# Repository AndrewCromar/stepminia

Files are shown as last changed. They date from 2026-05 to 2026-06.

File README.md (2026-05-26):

# Stepminia

Desktop finger stepmania dance-pad.

Assebly instructions [here](ASSEMBLY.md).

## PCB

Made in Kicad. Find the production files in the pcb folder to have it manufacured (JLCPCB).

You may notice the simple and integrated pcbs. This is because I wanted to learn how to integrate a microcontroller (rp2040) into my pcb design.. but when I went to have it made it was gonna cost $100! Its not that much but I have other things I wanna buy right now. So I made the simple version that just has holes for a Waveshare Zero to be soldered on.

## Firmware

The firmware is in the firmware folder and there will likly be a compiled version of it also in that folder.

> Wow really I had no clue the firmware would be in that folder bro.

## CAD

Right now I'm making the cad stuff in OnShape so I dont have files for it. I'll download the stls and put them in the cad folder when I'm done with them.

> I also my link to the OnShape files and/or download the files as solidworks parts if I can so people can make changes.

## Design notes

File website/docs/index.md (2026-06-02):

# Stepminia

Mini Stepmania dance-pad for desktop finger gaming.

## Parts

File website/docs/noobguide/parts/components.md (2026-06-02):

# Components

Gather the following components.

| Part | Count | Amazon Link | Image |
| ---- | ----- | --- | ----- |
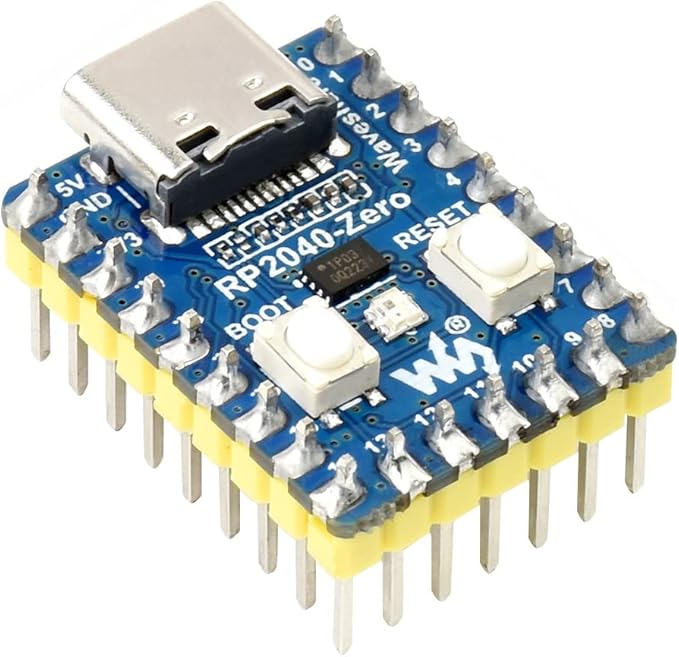
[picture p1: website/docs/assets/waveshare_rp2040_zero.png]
WaveShare RP2040-Zero
| WaveShare RP2040-Zero with Header | 1x | [link](https://a.co/d/0eX9dTef) |  |
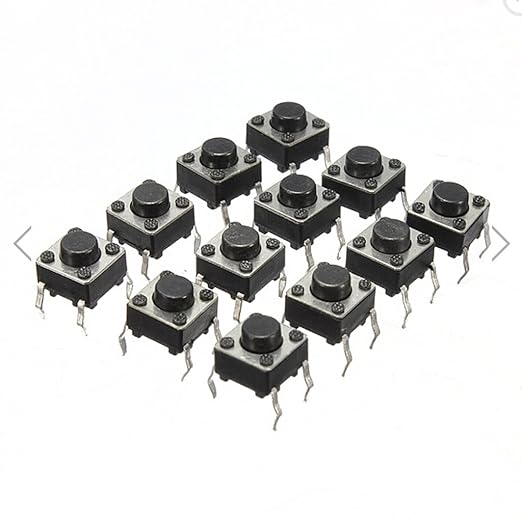
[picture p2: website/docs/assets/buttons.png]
Buttons
| Buttons | 2x | [link](https://a.co/d/03LZRInP) |  |
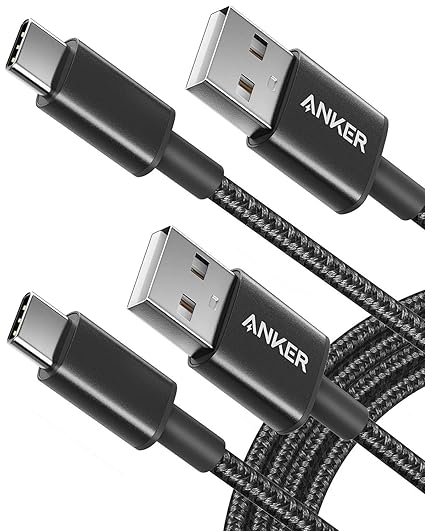
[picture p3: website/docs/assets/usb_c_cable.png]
USB-C cable
| USB-C Cable | 1x | [link](https://a.co/d/04qqzBDn) |  |

!!! note
    The links are recommended parts. You can find your own source to buy them if you want.

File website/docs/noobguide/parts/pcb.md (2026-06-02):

# PCB

The pcb (or circuit board) will be the main part that is needed for the device to work.

This section will guide you through downloading the files to having them manufactured.

## Download

[Click here to download the production files.](https://github.com/AndrewCromar/stepminia/raw/main/pcb/simple/production.zip)

## Manufacturing via JLC

1. [Open JLCPCB.](https://jlcpcb.com/)
2. Sign in or create an account.
3. Click the `Order Now` button.
4. Click the `Add gerber file` button and select the `production.zip` file you just downloaded.
5. You can leave all the settings default.
6. Click the `Save To Cart` button.
7. Go to your cart and checkout via the `Secure Checkout` button.

Your pcb has been ordered!

## Example

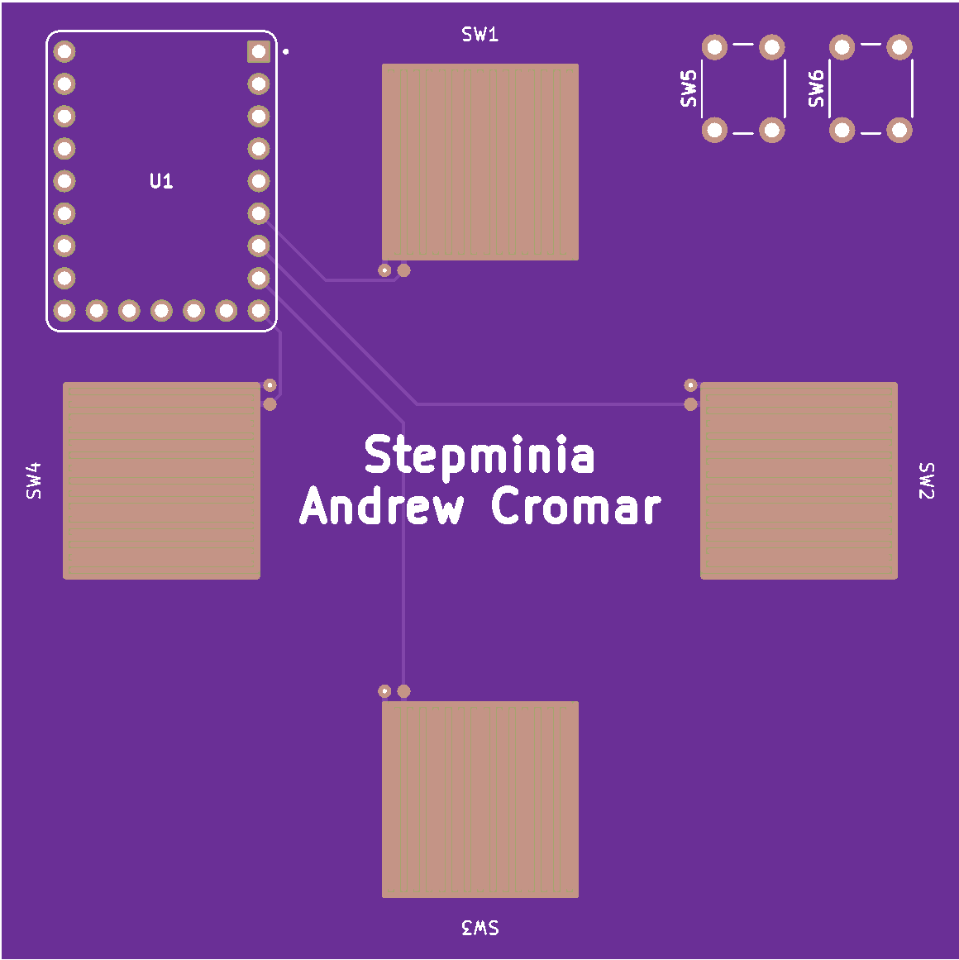
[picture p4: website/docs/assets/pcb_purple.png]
USB-C cable


!!! note
    Your pcb will likly be green but you can choose the color at step 5.

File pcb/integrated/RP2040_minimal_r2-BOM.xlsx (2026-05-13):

RP2040_minimal_r2 BOM
Item | Quantity | Reference | Part | Voltage | Current | Power | Material | Size | Tolerance | Manufacturer | Manuf. Part # | Description | Notes
1 | 3 | C1,C4,C17 | 10u | 16V |  |  | X5R | 0805_2012Metric | 10% | Murata | GRM21BR61C106KE15K | CAP CER 10UF 16V X5R 0805 | Or equivalent
2 | 2 | C2, C3 | 15p | 50V |  |  | C0G | 0402_1005Metric | 5% | Murata | GCM1555C1H150JA16D | CAP CER 15PF 50V C0G/NP0 0402 | Or equivalent
3 | 10 | C5, C6, C7, C9, C11, C12, C13, C14, C15, C16 | 100n | 25V |  |  | X7R | 0402_1005Metric | 10% | Murata | GRM155R71E104KE14J | CAP CER 0.1UF 25V X7R 0402 | Or equivalent
4 | 2 | C8, C10 | 1u | 10V |  |  | X6S | 0402_1005Metric | 10% | Murata | GRM155C81A105KA12D | CAP CER 1UF 10V X6S 0402 | Or equivalent
5 | 1 | J1 | USB_B_Micro |  |  |  |  |  |  | Amphenol | 10103594-0001LF | CONN RCPT USB2.0 MICRO B SMD R/A | Or equivalent
6 | 1 | J2 | 1x2 way header |  |  |  |  |  |  | Samtec | TSW-102-23-T-S | 2.54mm pin header 1x2 | Or equivalent
7 | 2 | J3, J4 | 2x18 way header |  |  |  |  |  |  | Samtec | TSW-118-23-T-D | 2.54mm pin header 2x18 | Or equivalent
8 | 2 | R1, R5 | 1k |  |  | 63mW |  | 0402_1005Metric | 1% | Yageo | RC0402FR-071KP | RES SMD 1K OHM 1% 1/16W 0402 | Or equivalent
9 | 1 | R2 | DNF |  |  |  |  | 0402_1005Metric |  |  |  |  | Do Not Fit
10 | 2 | R3, R4 | 27.4 |  |  | 63mW |  | 0402_1005Metric | 1% | Yageo | RC0402FR-0727R4L | RES SMD 27.4 OHM 1% 1/16W 0402 | Or equivalent
11 | 1 | U1 | NCP1117-3.3 |  |  |  |  | SOT-223-3 |  | ON Semiconductor | NCP1117ST33T3G | IC REG LINEAR 3.3V 1A SOT223
12 | 1 | U2 | W25Q128JVS |  |  |  |  | SOIC-8 |  | Winbond | W25Q128JVSIQ TR | IC FLASH 128M SPI 133MHZ 8SOIC
13 | 1 | U3 | RP2040 |  |  |  |  | QFN56 |  | Raspberry Pi | RP2040
14 | 1 | Y1 | ABM8-272-T3 |  |  |  |  | SMD_3225 |  | Abracon | ABM8-272-T3 | CRYSTAL 12.0000MHZ 3.2x2.5MM SMD

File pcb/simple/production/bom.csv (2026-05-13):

Designator | Footprint | Quantity | Value | LCSC Part #
SW1 | DDR_CONTACT | 1 | DDR_North
SW2 | DDR_CONTACT | 1 | DDR_East
SW3 | DDR_CONTACT_MIRROR | 1 | DDR_South
SW4 | DDR_CONTACT_MIRROR | 1 | DDR_West
SW5 | SW_PUSH_6mm | 1 | SW_Pause
SW6 | SW_PUSH_6mm | 1 | SW_Start
U1 | MODULE_RP2040-ZERO | 1 | RP2040-ZERO

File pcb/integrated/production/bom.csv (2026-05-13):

Designator | Footprint | Quantity | Value | LCSC Part #
C1, C17, C4 | 0805 | 3 | 10u | C440198
C10, C8 | 0402 | 2 | 1u | C29266
C11, C12, C13, C14, C15, C16, C5, C6, C7, C9 | 0402 | 10 | 100n | C60474
C2, C3 | 0402 | 2 | 15p | C86285
J2 | PinHeader_1x02_P2.54mm_Vertical | 1 | Conn_01x02
J3 | USB_C_Receptacle_GCT_USB4105-xx-A_16P_TopMnt_Horizontal | 1 | USB_C_Receptacle | C2765186
R1, R5 | 0402 | 2 | 1k | C106235
R2 | 0402 | 1 | 10k | C60490
R3, R4 | 0402 | 2 | 27 | C138021
R6, R7 | 0402 | 2 | 5.1k | C105872
SW1 | DDR_CONTACT_MIRROR | 1 | DDR_North
SW2 | DDR_CONTACT | 1 | DDR_South
SW3 | DDR_CONTACT | 1 | DDR_East
SW4 | DDR_CONTACT | 1 | DDR_West
U1 | SOT-223-3_TabPin2 | 1 | NCP1117-3.3_SOT223 | C26537
U2 | SOIC-8_5.23x5.23mm_P1.27mm | 1 | W25Q128JVS | C113767
U3 | RP2040-QFN-56 | 1 | RP2040 | C2040
Y1 | Crystal_SMD_3225-4Pin_3.2x2.5mm | 1 | ABM8-272-T3 | C20625731

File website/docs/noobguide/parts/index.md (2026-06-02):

# Gathering Parts

First you will need to gather all the parts to build your pad.

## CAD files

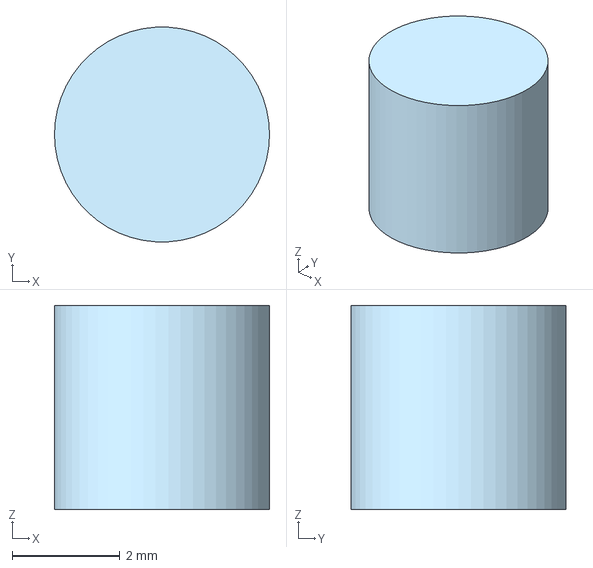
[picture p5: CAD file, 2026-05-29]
cad/Spacer - Spacer.step
4.00 x 3.99 x 3.80 mm

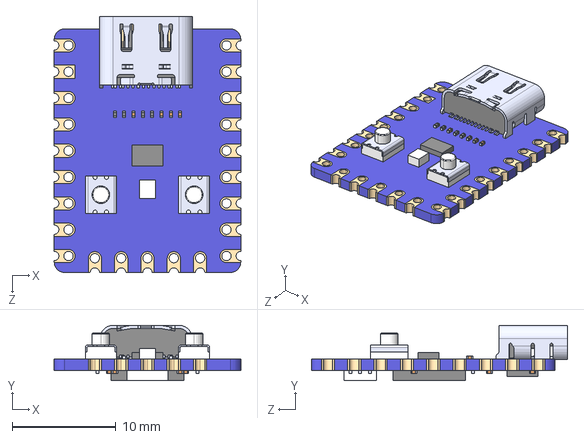
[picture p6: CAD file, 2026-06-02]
pcb/simple/RP2040-ZERO/RP2040-ZERO.step
18.0 x 5.35 x 24.7 mm

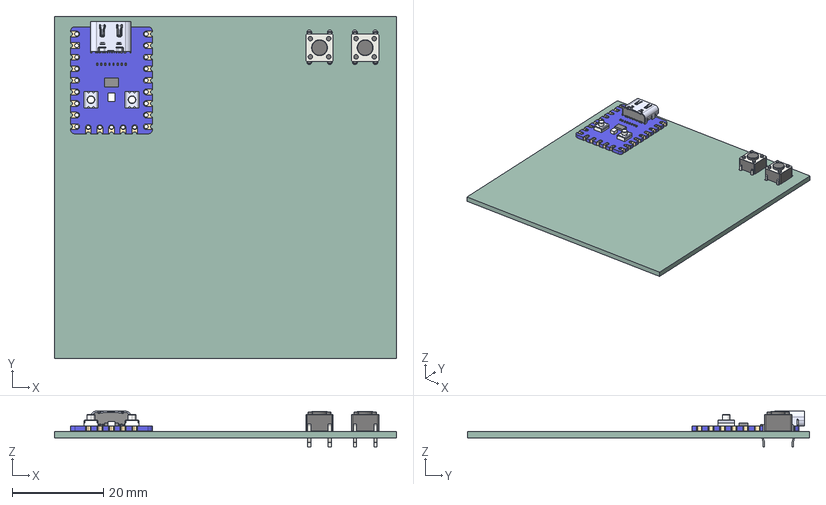
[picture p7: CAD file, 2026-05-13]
pcb/simple/stepminia_pcb.step
75.0 x 75.0 x 7.85 mm
RP2040-ZERO
SW_PUSH_6mm x 2
pcb_PCB

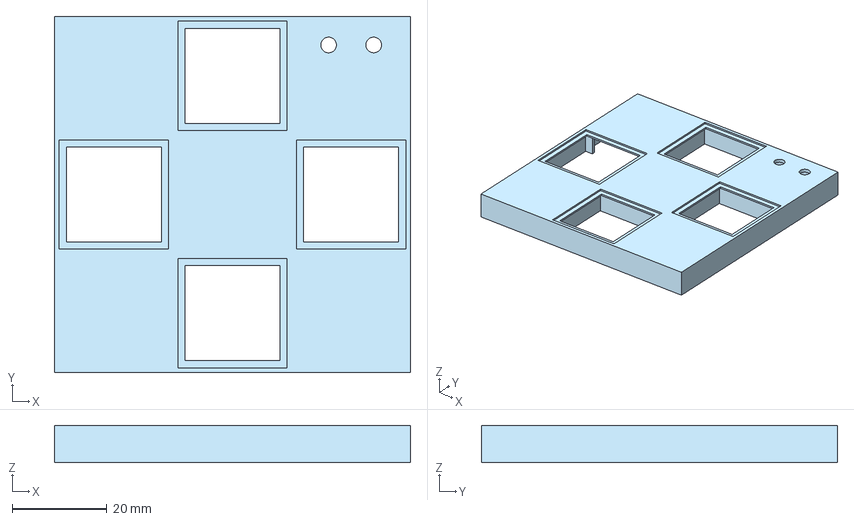
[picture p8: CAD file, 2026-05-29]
cad/All Nonants.step
75.0 x 75.0 x 7.80 mm

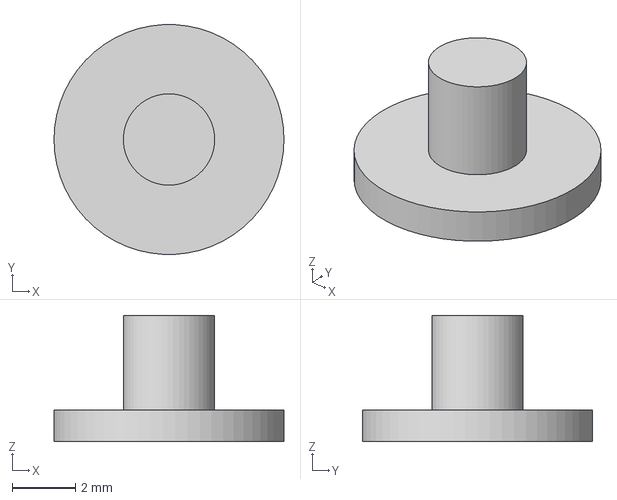
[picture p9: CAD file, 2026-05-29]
cad/Button - Button.step
7.30 x 7.29 x 4.00 mm

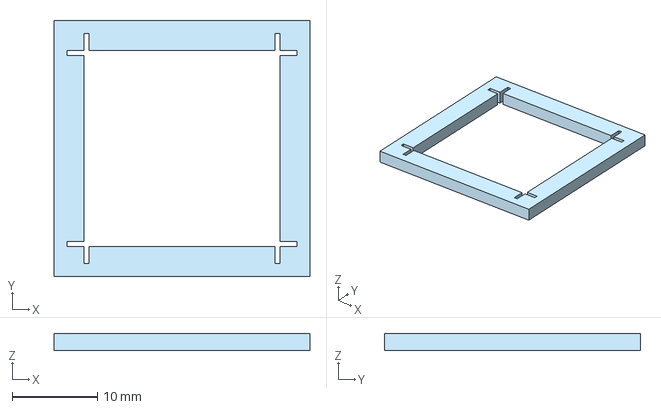
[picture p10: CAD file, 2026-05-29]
cad/Pad Guide - Pad Guide.step
30.0 x 30.0 x 2.00 mm

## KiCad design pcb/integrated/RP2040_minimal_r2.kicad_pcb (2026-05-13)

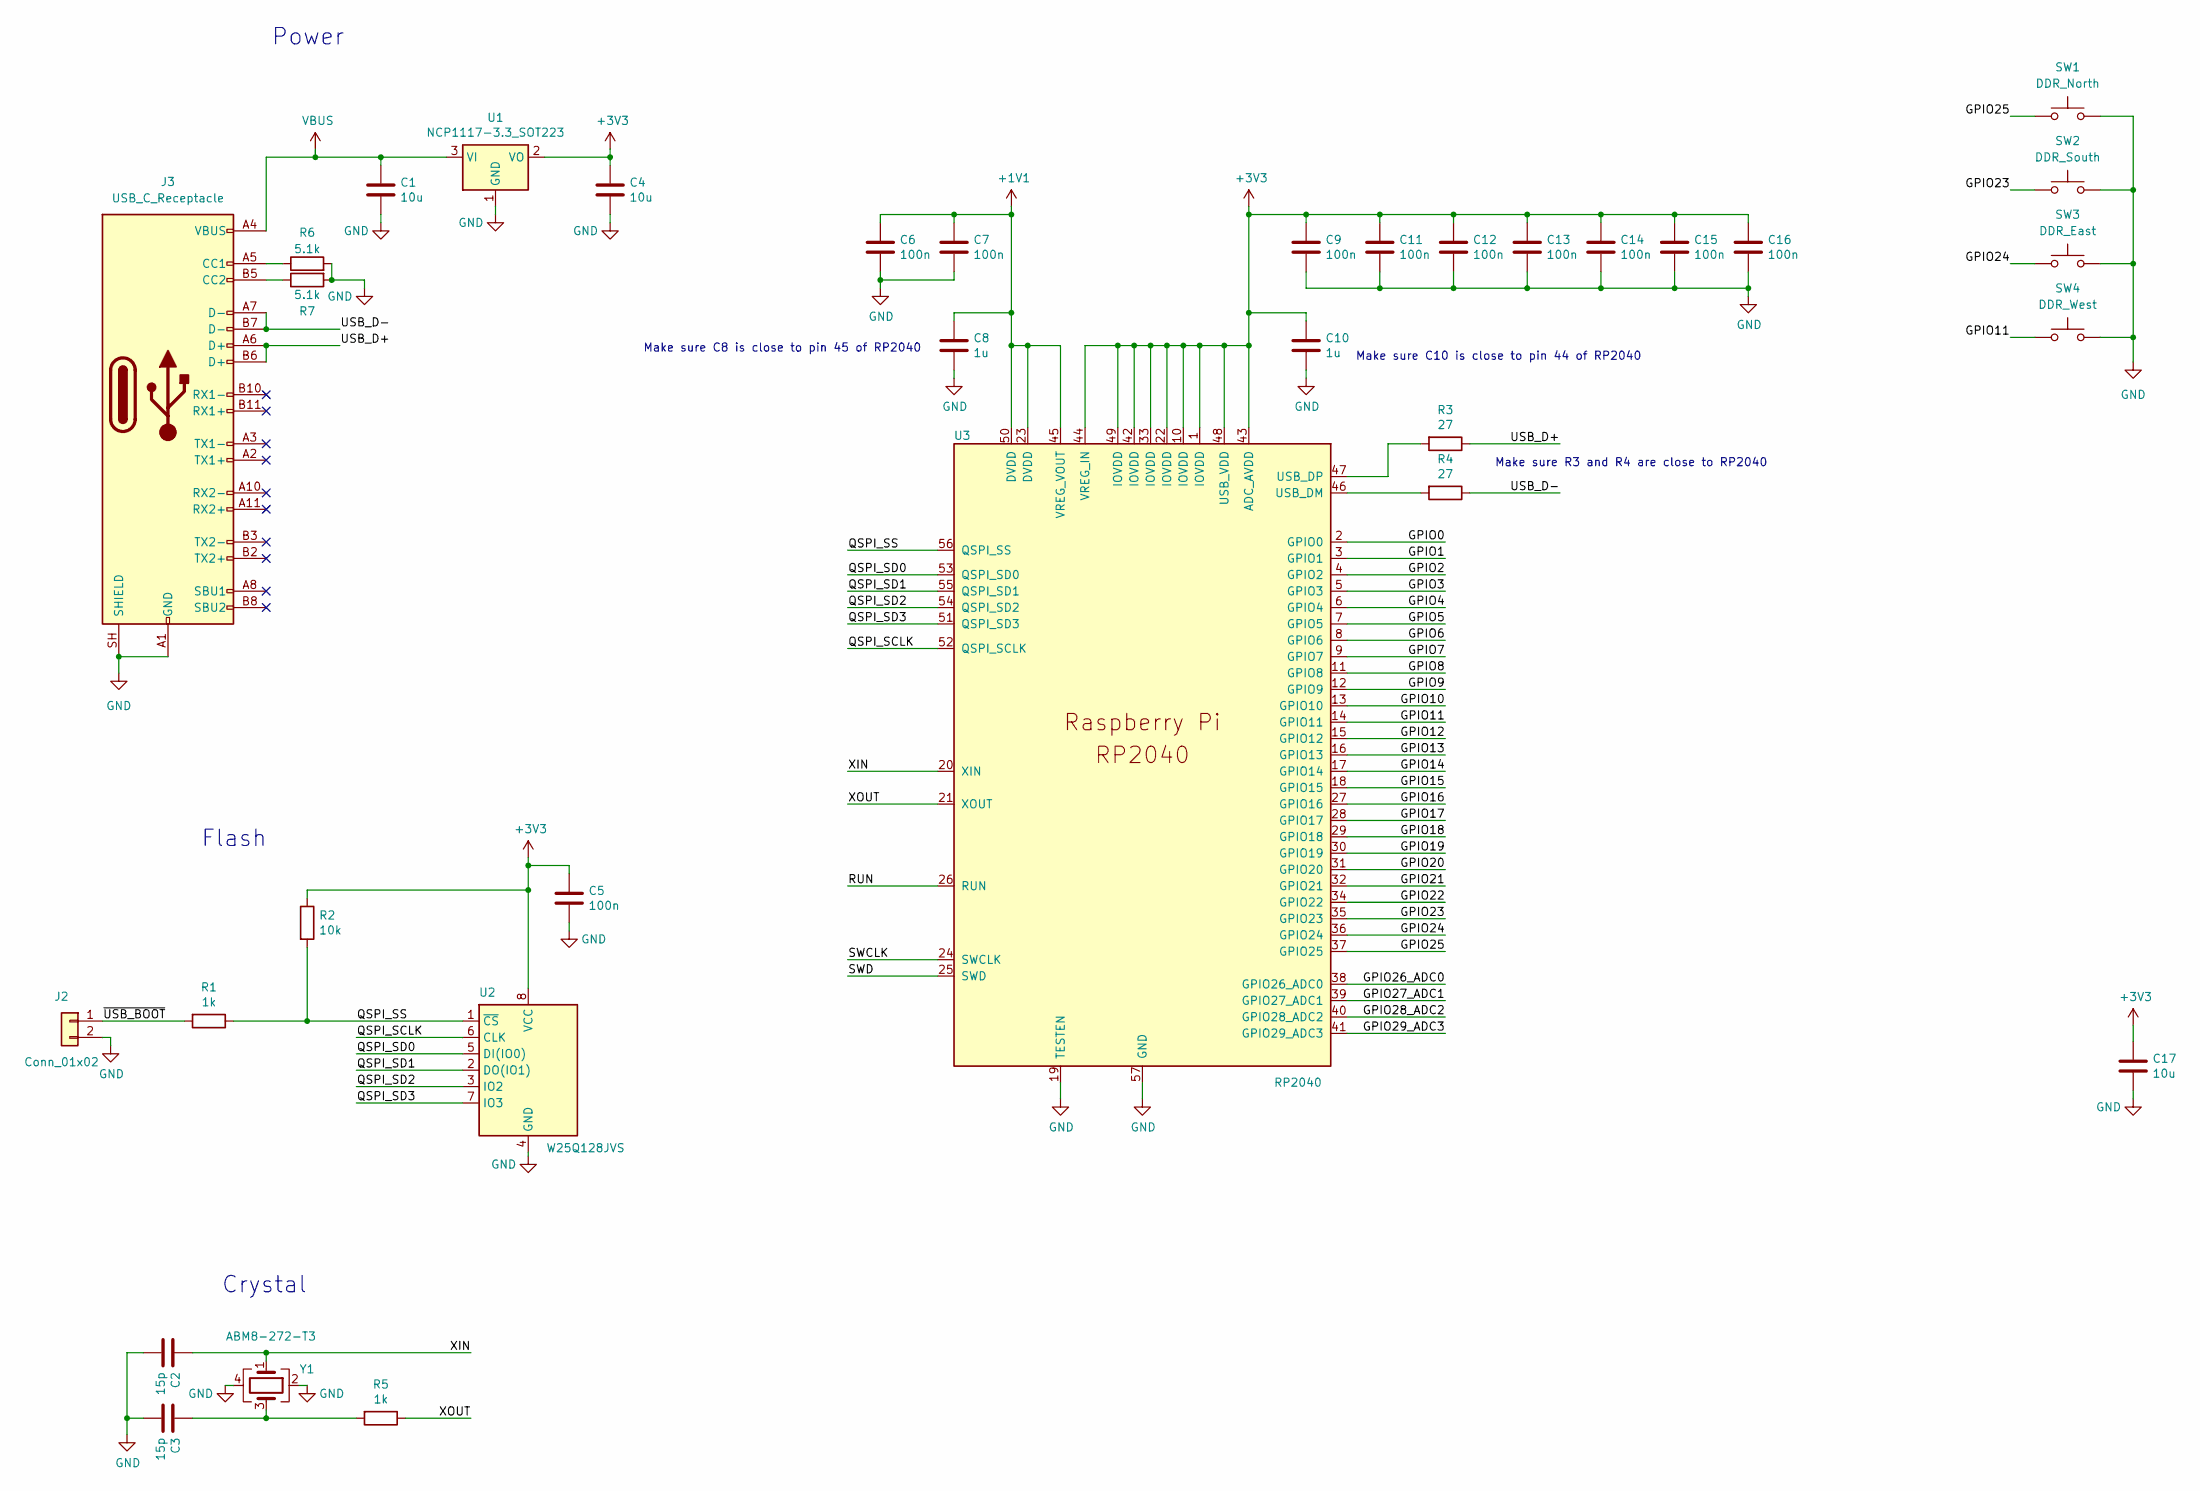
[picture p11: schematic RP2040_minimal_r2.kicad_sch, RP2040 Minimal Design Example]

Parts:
C1, C4, C17: 10u; C_0805_2012Metric; LCSC C440198
C2, C3: 15p; C_0402_1005Metric; LCSC C86285
C5, C6, C7, C9, C11, C12, C13, C14, C15, C16: 100n; C_0402_1005Metric; LCSC C60474
C8, C10: 1u; C_0402_1005Metric; LCSC C29266
J2: Conn_01x02; PinHeader_1x02_P2.54mm_Vertical
J3: USB_C_Receptacle; USB_C_Receptacle_GCT_USB4105-xx-A_16P_TopMnt_Horizontal; LCSC C2765186
R1, R5: 1k; R_0402_1005Metric; LCSC C106235
R2: 10k; R_0402_1005Metric; LCSC C60490
R3, R4: 27; R_0402_1005Metric; LCSC C138021
R6, R7: 5.1k; R_0402_1005Metric; LCSC C105872
SW1: DDR_North; DDR_CONTACT_MIRROR
SW2: DDR_South; DDR_CONTACT
SW3: DDR_East; DDR_CONTACT
SW4: DDR_West; DDR_CONTACT
U1: NCP1117-3.3_SOT223; SOT-223-3_TabPin2; LCSC C26537
U2: W25Q128JVS; SOIC-8_5.23x5.23mm_P1.27mm; LCSC C113767
U3: RP2040; RP2040-QFN-56; LCSC C2040
Y1: ABM8-272-T3; Crystal_SMD_3225-4Pin_3.2x2.5mm; LCSC C20625731

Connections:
+1V1: C6.1, C7.1, C8.1, U3.23 (DVDD), U3.45 (VREG_VOUT), U3.50 (DVDD)
+3V3: C4.1, C5.1, C9.1, C10.1, C11.1, C12.1, C13.1, C14.1, C15.1, C16.1, C17.1, R2.1, U1.2 (VO), U2.8 (VCC), U3.1 (IOVDD), U3.10 (IOVDD), U3.22 (IOVDD), U3.33 (IOVDD), U3.42 (IOVDD), U3.43 (ADC_AVDD), U3.44 (VREG_IN), U3.48 (USB_VDD), U3.49 (IOVDD)
/GPIO0: U3.2 (GPIO0)
/GPIO1: U3.3 (GPIO1)
/GPIO2: U3.4 (GPIO2)
/GPIO3: U3.5 (GPIO3)
/GPIO4: U3.6 (GPIO4)
/GPIO5: U3.7 (GPIO5)
/GPIO6: U3.8 (GPIO6)
/GPIO7: U3.9 (GPIO7)
/GPIO8: U3.11 (GPIO8)
/GPIO9: U3.12 (GPIO9)
/GPIO10: U3.13 (GPIO10)
/GPIO11: SW4.1, U3.14 (GPIO11)
/GPIO12: U3.15 (GPIO12)
/GPIO13: U3.16 (GPIO13)
/GPIO14: U3.17 (GPIO14)
/GPIO15: U3.18 (GPIO15)
/GPIO16: U3.27 (GPIO16)
/GPIO17: U3.28 (GPIO17)
/GPIO18: U3.29 (GPIO18)
/GPIO19: U3.30 (GPIO19)
/GPIO20: U3.31 (GPIO20)
/GPIO21: U3.32 (GPIO21)
/GPIO22: U3.34 (GPIO22)
/GPIO23: SW2.1, U3.35 (GPIO23)
/GPIO24: SW3.1, U3.36 (GPIO24)
/GPIO25: SW1.1, U3.37 (GPIO25)
/GPIO26_ADC0: U3.38 (GPIO26_ADC0)
/GPIO27_ADC1: U3.39 (GPIO27_ADC1)
/GPIO28_ADC2: U3.40 (GPIO28_ADC2)
/GPIO29_ADC3: U3.41 (GPIO29_ADC3)
/QSPI_SCLK: U2.6 (CLK), U3.52 (QSPI_SCLK)
/QSPI_SD0: U2.5 (DI(IO0)), U3.53 (QSPI_SD0)
/QSPI_SD1: U2.2 (DO(IO1)), U3.55 (QSPI_SD1)
/QSPI_SD2: U2.3 (IO2), U3.54 (QSPI_SD2)
/QSPI_SD3: U2.7 (IO3), U3.51 (QSPI_SD3)
/QSPI_SS: R1.1, R2.2, U2.1 (~CS), U3.56 (QSPI_SS)
/RUN: U3.26 (RUN)
/SWCLK: U3.24 (SWCLK)
/SWD: U3.25 (SWD)
/USB_D+: J3.A6 (D+), J3.B6 (D+), R3.1
/USB_D-: J3.A7 (D-), J3.B7 (D-), R4.1
/XIN: C2.1, U3.20 (XIN), Y1.1
/XOUT: R5.1, U3.21 (XOUT)
/~USB_BOOT: J2.1, R1.2
GND: C1.2, C2.2, C3.2, C4.2, C5.2, C6.2, C7.2, C8.2, C9.2, C10.2, C11.2, C12.2, C13.2, C14.2, C15.2, C16.2, C17.2, J2.2, J3.A1 (GND), J3.A12 (GND), J3.B1 (GND), J3.B12 (GND), J3.SH (SHIELD), R6.2, R7.2, SW1.2, SW2.2, SW3.2, SW4.2, U1.1 (GND), U2.4 (GND), U3.19 (TESTEN), U3.57 (GND), Y1.2, Y1.4
unnamed: C3.1, R5.2, Y1.3
unnamed: J3.A5 (CC1), R6.1
unnamed: J3.B5 (CC2), R7.1
unnamed: R4.2, U3.46 (USB_DM)
unnamed: R3.2, U3.47 (USB_DP)
VBUS: C1.1, J3.A4 (VBUS), J3.A9 (VBUS), J3.B4 (VBUS), J3.B9 (VBUS), U1.3 (VI)

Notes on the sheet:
Power
Crystal
Make sure C8 is close to pin 45 of RP2040
Make sure C10 is close to pin 44 of RP2040
Make sure R3 and R4 are close to RP2040
Flash

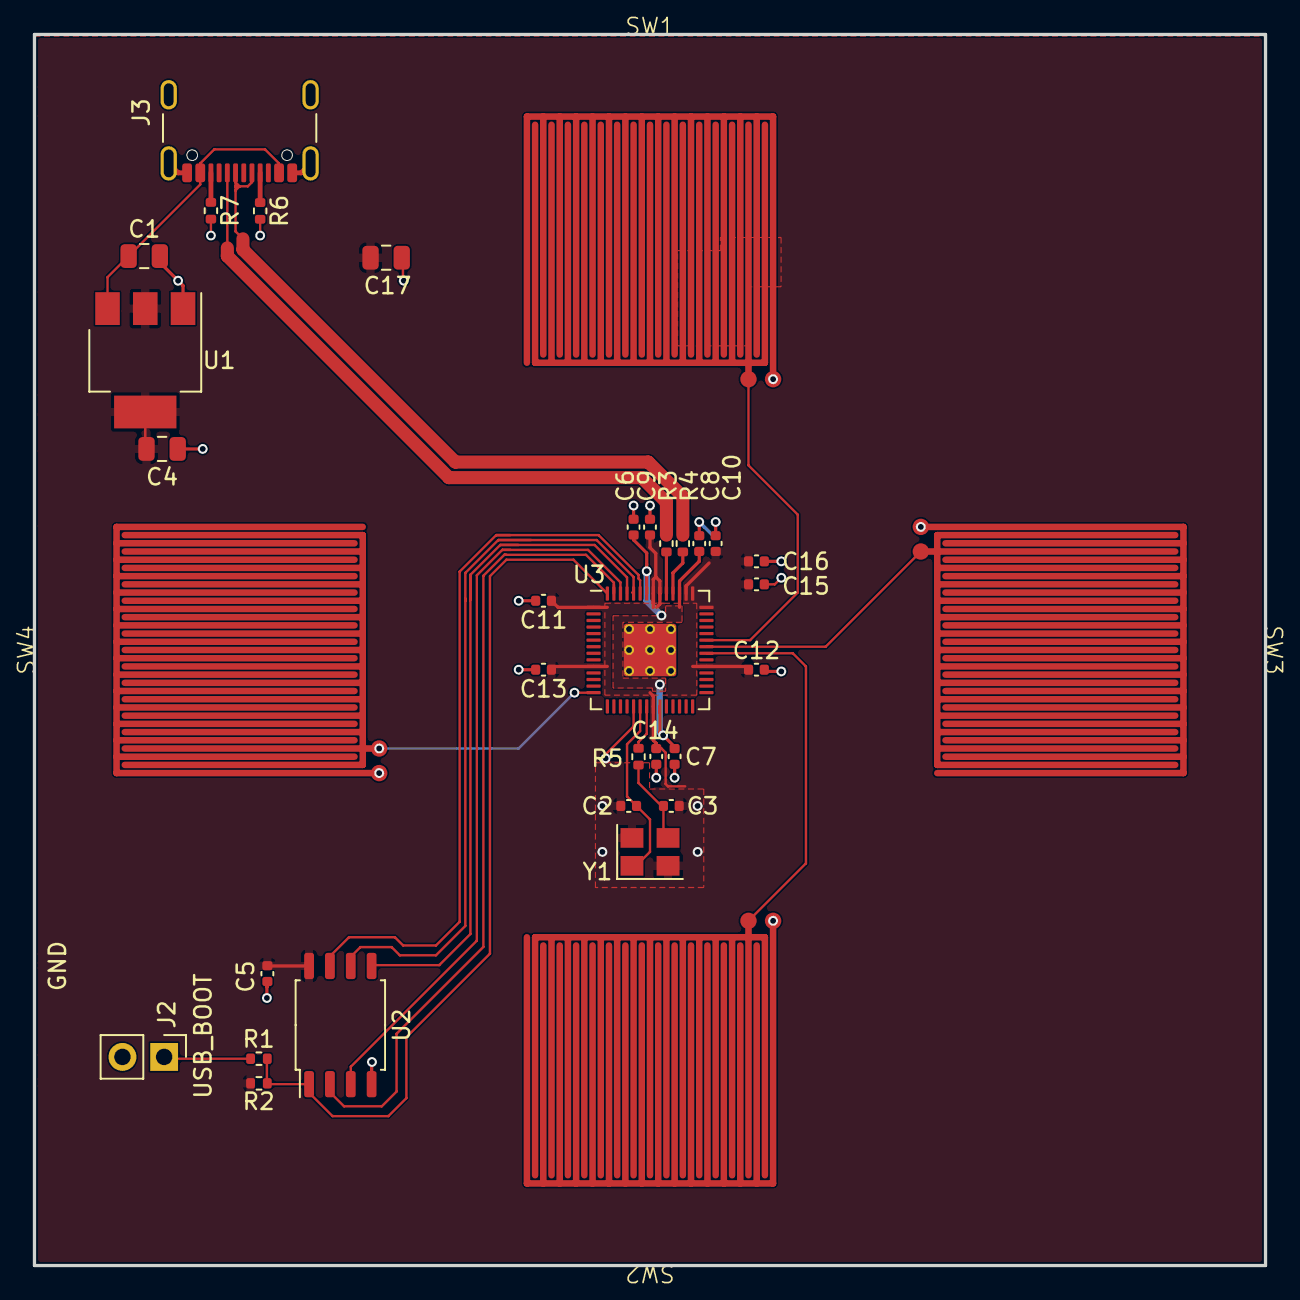
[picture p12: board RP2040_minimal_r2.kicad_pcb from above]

Board: 2 copper layers, 75.0 x 75.0 mm, 34 parts (0 on the bottom side), 24 nets.

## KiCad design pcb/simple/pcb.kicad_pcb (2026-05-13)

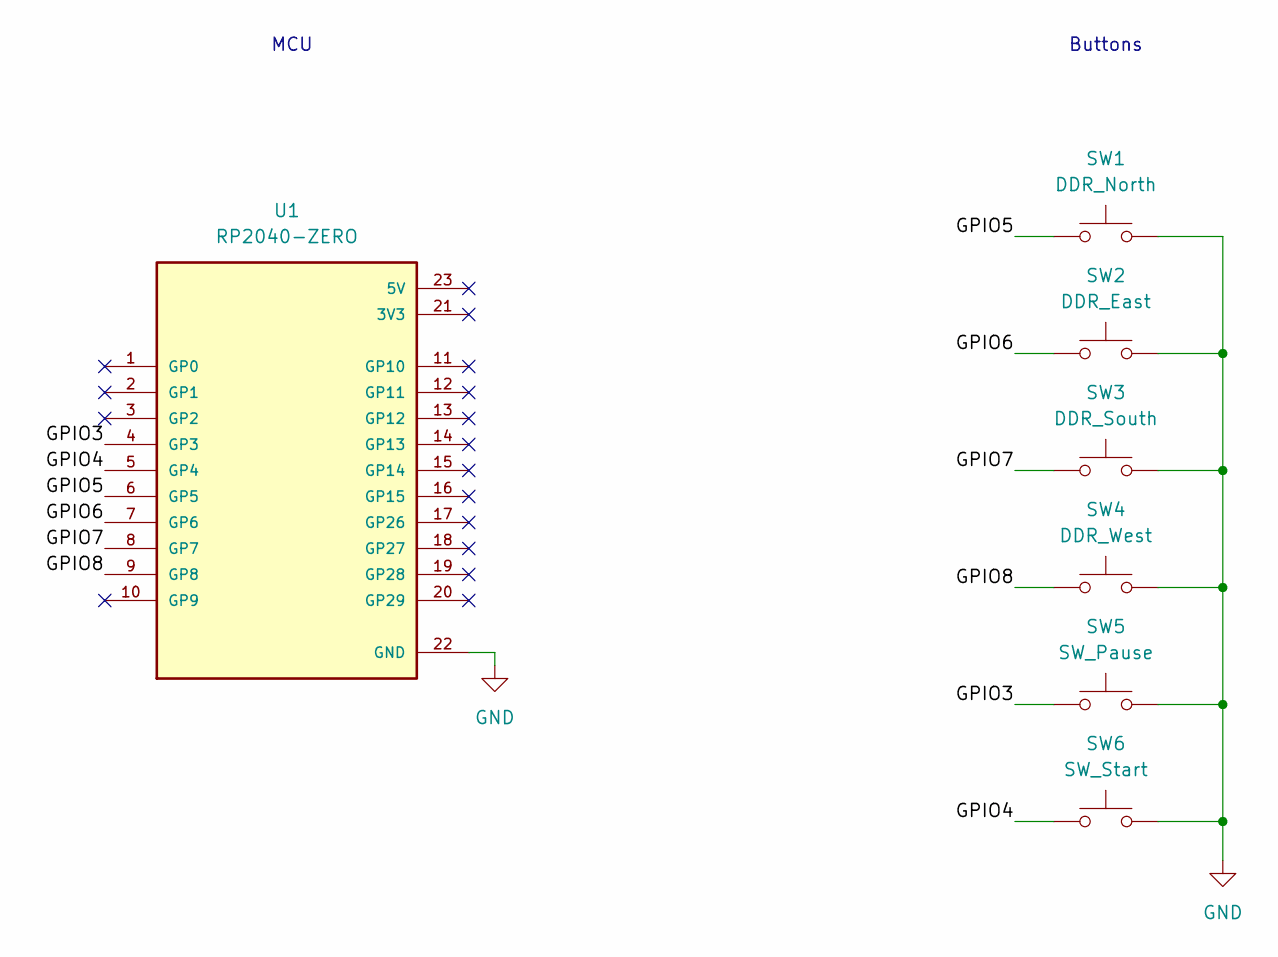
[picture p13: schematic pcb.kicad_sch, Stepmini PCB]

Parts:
SW1: DDR_North; DDR_CONTACT
SW2: DDR_East; DDR_CONTACT
SW3: DDR_South; DDR_CONTACT_MIRROR
SW4: DDR_West; DDR_CONTACT_MIRROR
SW5: SW_Pause; SW_PUSH_6mm
SW6: SW_Start; SW_PUSH_6mm
U1: RP2040-ZERO; MODULE_RP2040-ZERO; PARTREV NA

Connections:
/GPIO3: SW5.1, U1.4 (GP3)
/GPIO4: SW6.1, U1.5 (GP4)
/GPIO5: SW1.1, U1.6 (GP5)
/GPIO6: SW2.1, U1.7 (GP6)
/GPIO7: SW3.1, U1.8 (GP7)
/GPIO8: SW4.1, U1.9 (GP8)
GND: SW1.2, SW2.2, SW3.2, SW4.2, SW5.2, SW6.2, U1.22 (GND)

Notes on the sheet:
MCU
Buttons

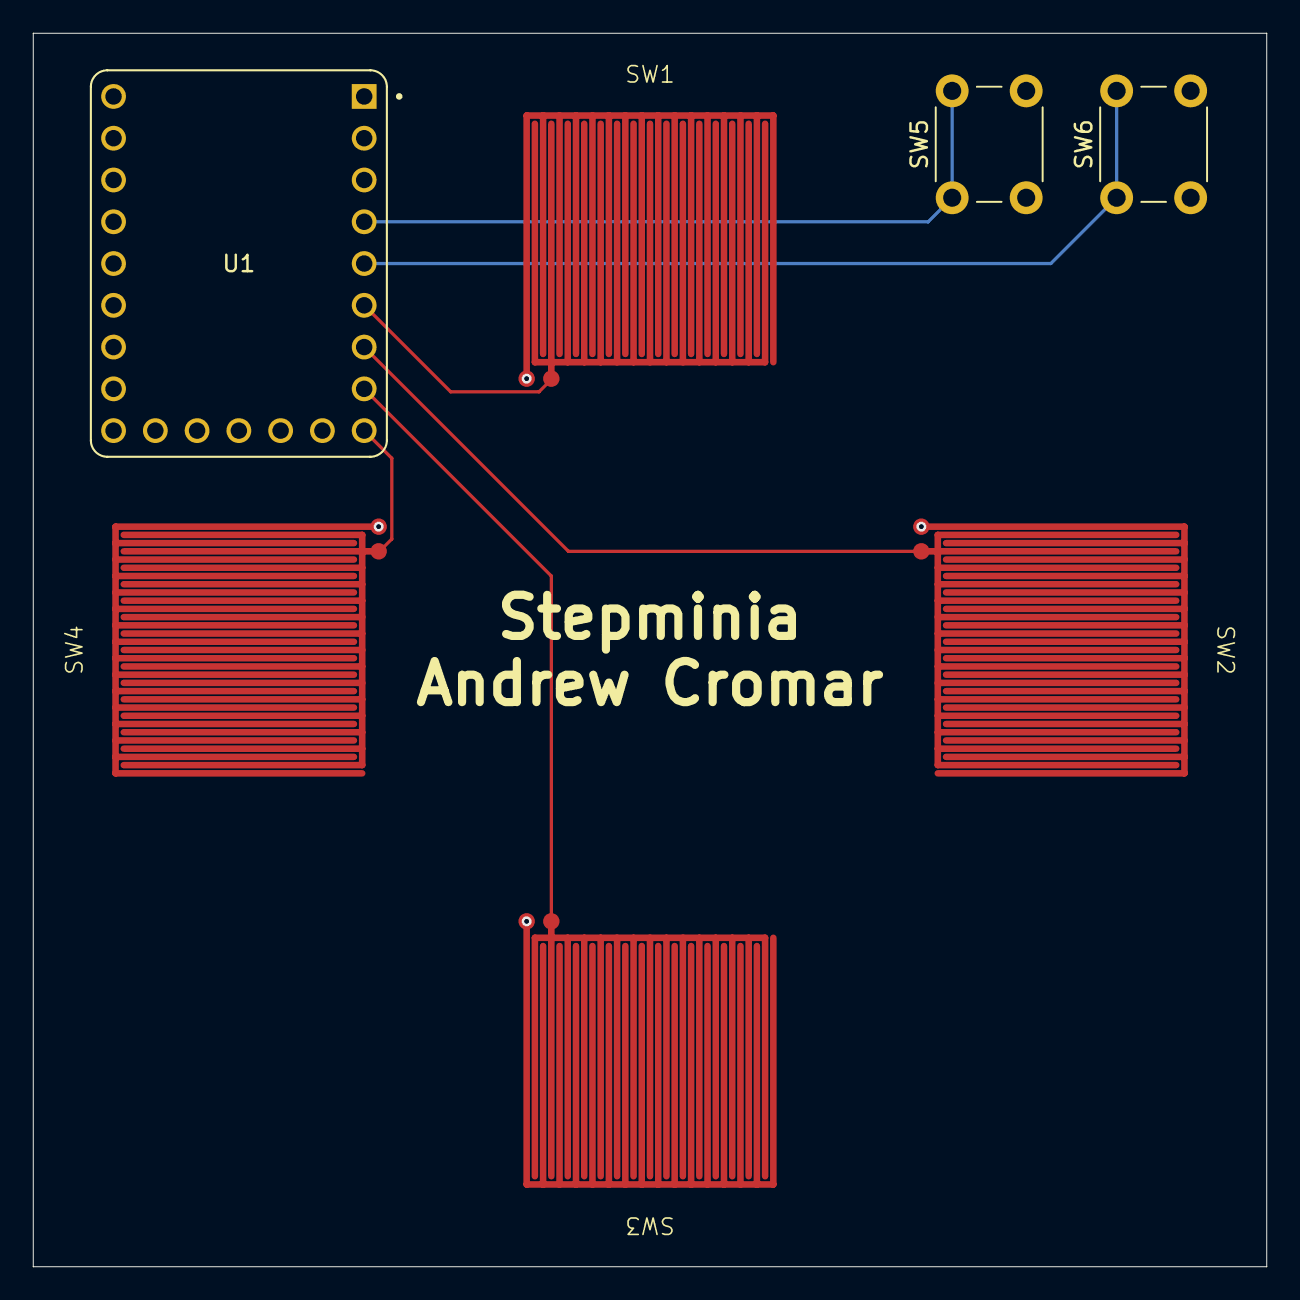
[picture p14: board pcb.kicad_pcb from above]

Board: 2 copper layers, 75.0 x 75.0 mm, 7 parts (0 on the bottom side), 7 nets.

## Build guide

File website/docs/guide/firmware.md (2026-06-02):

# Firmware

The firmware is the program that runs on the RP2040. Once it's installed, the
pad shows up to your computer as a plain USB keyboard, no drivers or extra
software needed. Each button or contact pad simply types a key.

## What it does

When you press a button (or bridge a contact pad), the pad sends a key press:

| Input | Key sent |
| --- | --- |
| Up | Arrow Up |
| Down | Arrow Down |
| Left | Arrow Left |
| Right | Arrow Right |
| Plus (+) | Enter |
| Minus (−) | Escape |

These are the keys Stepmania (and most rhythm games) use by default, so the pad
works out of the box.

## Get the firmware

The easy option is the **pre-compiled file**, a single `.uf2` you drag onto the
board, no tools required.

- [Download the pre-compiled `.uf2`](https://github.com/AndrewCromar/stepminia/raw/main/firmware/stepminia.uf2) — recommended.
- [Firmware source code](https://github.com/AndrewCromar/stepminia/tree/main/firmware) (`repo/firmware/`) — if you want to read or change it.

## Install it

1. **Unplug** the pad from your computer.
2. Hold down the `BOOTSEL` button on the RP2040, and *while holding it*, plug the
   pad back into your computer.
3. The pad mounts as a USB drive. You can
   let go of the button now.
4. **Drag the `.uf2` file onto that drive.**

The pad reboots automatically and the drive disappears, that's normal, it means
the firmware installed. It's now running as a keyboard.

## Test it

Press any button, or bridge two contact pads together (a strip of aluminum foil
works well), and check that the matching key registers. The
[keyboard tester](https://keyboard-tester.com/) site is a quick way to see your
presses live in the browser.

## Build it yourself (optional)

The source is a [PlatformIO](https://platformio.org/) project for the Waveshare
RP2040-Zero. With PlatformIO installed, open the `firmware/` folder and run:

```bash
pio run            # compile
pio run -t upload  # compile and flash a connected board
```

Compiling also produces a fresh `stepminia.uf2` you can install by hand using the
steps above.

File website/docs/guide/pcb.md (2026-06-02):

# PCB

The PCB is the heart of the pad. It carries the RP2040 microcontroller, contact pads, and buttons. There are two versions to choose from.

## Which version should I choose?

| Version | RP2040 | Best for |
| --- | --- | --- |
| **Simple** | A separate [Waveshare RP2040-Zero](https://www.waveshare.com/wiki/RP2040-Zero) board solders onto pads on the PCB. | Beginners, or anyone who'd rather solder one pre-made module than place lots of small parts. Cheaper to start, easier to assemble by hand. |
| **Integrated** | The RP2040 chip is mounted directly on the board, no second board needed. | A cleaner, single-board build. Requires placing many very small parts, so it's better suited to a PCB-assembly service or experienced solderers. |

Pick whichever matches your skill level and budget, both produce the same finished Stepminia pad.

## Getting the files

For each version you have two options:

- **Order it as-is**, download the ready-made JLCPCB production `.zip` and
  upload it straight to [JLCPCB](https://jlcpcb.com/) (or a similar fab house).
  This is the fast path.
- **Open or edit the design**, grab the [KiCad](https://www.kicad.org/) source
  if you want to inspect, modify, or regenerate the board yourself.

!!! note
    Using the ready-made production files is recommended.

### Simple

- [Download JLCPCB production files (.zip)](https://github.com/AndrewCromar/stepminia/raw/main/pcb/simple/production.zip).
- [KiCad source files](https://github.com/AndrewCromar/stepminia/tree/main/pcb/simple) (`repo/pcb/simple/`).

### Integrated

- [Download JLCPCB production files (.zip)](https://github.com/AndrewCromar/stepminia/raw/main/pcb/integrated/production.zip).
- [KiCad source files](https://github.com/AndrewCromar/stepminia/tree/main/pcb/integrated) (`repo/pcb/integrated/`).

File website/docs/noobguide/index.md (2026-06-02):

# Noob Guide

If you are a complete beginner, this is the guide for you. It will walk you through every step with a lot of details so you can build your own Stepmini pad with no experience.

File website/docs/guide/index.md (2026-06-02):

# Build your own

This guide walks through building your own Stepminia Pad from scratch.

It is designed to walk you through having no experience to having a fully working Stepmini pad.

!!! note "Work in progress"
    The guide is still being written. Steps will fill in over time — check back!

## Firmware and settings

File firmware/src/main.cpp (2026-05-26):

#include <Arduino.h>
#include <Adafruit_TinyUSB.h>
#include "buttons.h"
#include "debug_logger.h"
#include "keyboard_input.h"

Buttons buttons;
DebugLogger logger;
KeyboardInput keyboard;

void setup() {
  TinyUSBDevice.setManufacturerDescriptor("Andrew Cromar");
  TinyUSBDevice.setProductDescriptor("Stepminia");

  logger.begin();
  buttons.begin();
  keyboard.begin();
}

void loop() {
  buttons.update();
  keyboard.update(buttons);
  logger.logButtons(buttons);
  delay(10);
}

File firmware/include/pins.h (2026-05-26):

#pragma once

const int PIN_UP    = 5;
const int PIN_RIGHT = 6;
const int PIN_DOWN  = 7;
const int PIN_LEFT  = 8;

const int PIN_PLUS  = 4;
const int PIN_MINUS = 3;

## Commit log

2026-04-13 more pcb work
    [pcb.kicad_sch]
2026-04-13 even more pcb work
    [pcb.kicad_sch]
2026-04-13 more pcb stuff yay
    [pcb.kicad_pcb, pcb.kicad_sch]
2026-04-13 started routing pcb
    [pcb.kicad_pcb, pcb.kicad_sch]
2026-04-13 saving things for the night
    [pcb.kicad_sch]
2026-04-13 new version of the ddr pcb
2026-04-13 working on pcb even more
    [pcb.kicad_pcb, pcb.kicad_sch]
2026-04-15 make button lib
    [Tactile_Switch_4.2x3.2.step]
2026-04-15 work on it yay
    [pcb.kicad_pcb, pcb.kicad_sch]
2026-04-15 buttons on pcb
    [pcb.kicad_pcb]
2026-04-15 more schematic work
    grounds are gay :(
    [pcb.kicad_pcb]
2026-04-15 still working on it LOL
    [pcb.kicad_pcb, pcb.kicad_sch]
2026-04-16 working on usbc stuff
    [Tactile_Switch_4.2x3.2.step, pcb.kicad_pcb, pcb.kicad_sch]
2026-04-16 usbc almost done
    [pcb.kicad_pcb, pcb.kicad_sch]
2026-04-16 started working on voltage regulator
    [pcb.kicad_pcb, pcb.kicad_sch]
2026-04-16 start making footprint
2026-04-16 added it to the pcb
    [pcb.kicad_pcb, pcb.kicad_sch]
2026-04-16 added footprints to c
    [pcb.kicad_pcb, pcb.kicad_sch]
2026-04-16 wired some stuff
    [pcb.kicad_pcb]
2026-04-16 add vias and ground
    [pcb.kicad_pcb]
2026-04-16 usbc schematic done?
    [pcb.kicad_pcb, pcb.kicad_sch]
2026-04-16 usb c stuff
    [pcb.kicad_pcb]
2026-04-16 cleaned up old pcb_new and gitignore
    [pcb.kicad_pcb, pcb.kicad_sch]
2026-04-16 fixxed usbc stuff
    [pcb.kicad_pcb, pcb.kicad_sch]
2026-04-20 work on schematic a bit
    - power decoupling
    - organize
    [pcb.kicad_sch]
2026-04-20 add stuff to pcb
    [pcb.kicad_pcb]
2026-04-20 ddr footprint
2026-04-20 working on ddr contacts n stuff
    [pcb.kicad_pcb, pcb.kicad_sch]
2026-04-20 still doing stuff
    [pcb.kicad_pcb]
2026-04-20 Revert "still doing stuff"
    This reverts commit 534b6c4f653d7dddeed3be9c90f6de3e6d88290d.
    [pcb.kicad_pcb]
2026-04-20 fixed ddr contacts
    [pcb.kicad_pcb]
2026-04-20 work on schematic more
    [pcb.kicad_pcb, pcb.kicad_sch]
2026-04-20 working on pcb
    [pcb.kicad_pcb]
2026-04-21 working on new footprint
2026-04-21 working on schematic now
    [pcb.kicad_sch]
2026-04-21 button footprint
2026-04-21 work on schematic
    [pcb.kicad_sch]
2026-04-21 update pcb
    [pcb.kicad_pcb]
2026-04-21 lots of pcb work
    [pcb.kicad_pcb]
2026-04-21 more routing
    [pcb.kicad_pcb]
2026-04-21 even more pcb stuff
    [pcb.kicad_pcb, pcb.kicad_sch]
2026-04-21 closing up
    [pcb.kicad_sch]
2026-04-24 make footprint
    [pcb.kicad_sch]
2026-04-24 fix footprint
2026-04-24 work on pcb
    [pcb.kicad_pcb]
2026-04-24 work on pcb more
    [pcb.kicad_pcb]
2026-05-13 clear v2
    [pcb.kicad_pcb, pcb.kicad_sch]
2026-05-13 add rp minimal example
    [RP2040_minimal_r2-BOM.xlsx, RP2040_minimal_r2.kicad_pcb, RP2040_minimal_r2.kicad_sch]
2026-05-13 upt to newer kicad version
    [RP2040_minimal_r2.kicad_pcb, RP2040_minimal_r2.kicad_sch]
2026-05-13 add ddr contacts to pcb
    [RP2040_minimal_r2.kicad_pcb, RP2040_minimal_r2.kicad_sch]
2026-05-13 clean up pcb
    [RP2040_minimal_r2.kicad_pcb, RP2040_minimal_r2.kicad_sch]
2026-05-13 add gnd zone
    [RP2040_minimal_r2.kicad_pcb, RP2040_minimal_r2.kicad_sch]
2026-05-13 add usbc to schematic
    [RP2040_minimal_r2.kicad_pcb, RP2040_minimal_r2.kicad_sch]
2026-05-13 finish pcb i think
    [RP2040_minimal_r2.kicad_pcb, RP2040_minimal_r2.kicad_sch]
2026-05-13 move some stuff a bit
    [RP2040_minimal_r2.kicad_pcb]
2026-05-13 start adding lcsc numbers
    [RP2040_minimal_r2.kicad_sch]
2026-05-13 add rest of lcsc numbers
    [RP2040_minimal_r2.kicad_pcb, RP2040_minimal_r2.kicad_sch]
2026-05-13 build prod files
    [RP2040_minimal_r2.kicad_pcb, bom.csv, designators.csv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]
2026-05-13 move some files
    [RP2040_minimal_r2-BOM.xlsx, RP2040_minimal_r2.kicad_pcb, RP2040_minimal_r2.kicad_sch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]
2026-05-13 finish pcb
    [bom.csv, designators.csv, pcb.kicad_pcb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]
2026-05-29 add cad files
    [All Nonants.step, Button - Button.step, Pad Guide - Pad Guide.step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]
2026-06-02 Use favicon as header logo
    Replaces the default material/library icon in the top-left with the
    project favicon.
2026-06-02 oganize pcb files
    [RP2040-ZERO.step, RP2040_minimal_r2.kicad_pcb, RP2040_minimal_r2.kicad_sch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]
2026-06-02 finish up pcb page of the guide
